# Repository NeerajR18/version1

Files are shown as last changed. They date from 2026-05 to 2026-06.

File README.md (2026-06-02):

Zine

# version1

version1 is a TKL(TenKeyLess) Mechanical Keyboard with Kalih Hotswappable sockets and Cherry MX Black switches.

The keyboard features a fully custom made PCB with 87 standard TKL keys and 4 macrokeys. The keyboard is wired, using a USB-C port.
version1 uses the STM32F072CBT6 at its core.

The PCB was designed in KiCad and the case was designed in Autodesk Fusion. Fusion was also used to render images of the design.
The footprints for the switches have been taken from the marbastlib library - https://github.com/ebastler/marbastlib

Made for Hack Club Fallout.
Note: This is still a WIP. Please copy anything at your own risk or do not copy at all.
## Why build this?
This keyboard was designed as a deep dive into electronics as a beginner and to learn more about CAD. 

I also have never used mechanical keyboards, so I want this to act as my entry point to mechanical keyboards.

## Repository Guide
```
version1/
|── PCB/
|   |── version1.kicad_pro
|   |── version1.kicad_pcb
|   |── version1.kicad_sch
|   └── version1_matrix.kicad_sch
|
|── CAD/
|   |── version1.f3d
|   |── version1-assembly.step
|   |── version1.fbx
|   |
|   |──── version1-base/
|   |     |── version1-base-left.step
|   |     |── version1-base-middle.step
|   |     └── version1-base-right.step
|   |
|   └──── version1-plate/
|         |── version1-plate-left.step
|         └── version1-plate-right.step
| 
|── Production/   
|    |── gerbers.zip/
|    |
|    |── STL Files/
|    |   |─── version1-base/
|    |   |    |── version1-base-left.stl
|    |   |    |── version1-base-middle.stl
|    |   |    └── version1-base-right.stl
|    |   |
|    |   └─── version1-plate/
|    |        |── version1-plate-left.stl
|    |        └── version1-plate-right.stl
|    |
|    └── STEP Files/
|           |─── version1-base/
|           |      |── version1-base-left.step
|           |      |── version1-base-middle.step
|           |      └── version1-base-right.step
|           |
|           └──── version1-plate/
|                   |── version1-plate-left.step
|                   └── version1-plate-right.step
|
|── Assets/
|    |── Keycaps/
|    |── MX Switch/
|    |── Rotary Encoder/
|    |── Type-C/
|    └── version1.fbx
|
|── qmk_firmware/
|    └── version1/
|       |── keymaps/
|       |   └── keymaps/
|       |       └── default/
|       |           └── keymap.c
|       |── config.h
|       |── keyboard.json
|       └── readme.md
|
|── BOM.csv
|── Zine.pdf
└── README.md
```

## Schematic
##### Overall Schematic


##### Key matrix


## PCB
##### PCB Front without GND Plane


##### PCB Front with GND Plane


##### PCB Back without GND Plane


##### PCB Back with GND Plane


## CAD
The case has been split into two parts on the plate and 3 parts on the base to accomodate 3D printed parts. The plates and base have small pegs and holes for assembly.

#### Full Assembly
##### Top View


#####  Side View


#### Top Plate
##### Top View


#####  Side View


#### Base
##### Top View


#####  Side View


## Renders 
##### Top view
version1-top-render

##### Side view
version1-side-render
version1-right-render

## Build Guide
To be updated with pictures after IRL build.

## Bill of Materials

| MPN | Designator | Quantity | Unit Price (USD) | Price (Ext.) | Package | LCSC Part Number | Link |
|-----|---|---|---|---|---|---|---|
| CPG151101S11-2 | MX1-M91 | 100 | 0.0344 | 3.44 | - | C49352235 | https://www.lcsc.com/product-detail/C49352235.html |
| STM32F072CBT6 | U1 | 1 | 2.212 | 2.21 | LQFP-48(7x7) | C81720 | https://www.lcsc.com/product-detail/C81720.html |
| XC6206P332MR-G | U2 | 5 | 0.1119 | 0.56 | SOT-23-3L | C5446 | https://www.lcsc.com/product-detail/C5446.html |
| PRTR5V0U2X-ES | D1 | 5 | 0.0404 | 0.2 | SOT-143 | C5180302 | https://www.lcsc.com/product-detail/C5180302.html |
| 1N4148W | D2-D93 | 100 | 0.0058 | 0.58 | SOD-123 | C917030 | https://www.lcsc.com/product-detail/C917030.html |
| TYPE-C 16PIN 2MD(073) | J1 | 20 | 0.0747 | 1.49 | SMD | C2765186 | https://www.lcsc.com/product-detail/C2765186.html |
| TS-1088-AR02016 | SW1, SW2 | 10 | 0.0538 | 0.54 | SMD, 4x3mm | C720477 | https://www.lcsc.com/product-detail/C720477.html |
| EC11E15244B2 | SW3 | 1 | 2 | 2 | Through Hole | C470754 | https://www.lcsc.com/product-detail/C470754.html |
| 1206L050YR | F1 | 10 | 0.0622 | 0.62 | 1206 | C163512 | https://www.lcsc.com/product-detail/C163512.html |
| RC0402FR-075K1L | R1, R2 | 100 | 0.0009 | 0.09 | 0402 | C105872 | https://www.lcsc.com/product-detail/C105872.html |
| RC0402FR-0710KL | R3 | 100 | 0.0008 | 0.08 | 0603 | C60490 | https://www.lcsc.com/product-detail/C60490.html |
| CC0402KRX7R7BB104 | C1, C4, C5, C6, C7, C8, C10 | 100 | 0.0011 | 0.11 | 0402 | C60474 | https://www.lcsc.com/product-detail/C60474.html |
| CL10B105KA8NNNC | C2, C3 | 50 | 0.0069 | 0.35 | 0603 | C29936 | https://www.lcsc.com/product-detail/C29936.html |
| CL10A106KP8NNNC | C9 | 50 | 0.0103 | 0.52 | 0603 | C19702 | https://www.lcsc.com/product-detail/C19702.html |
| Cherry MX Black Switches [Pack of 10] | - | 10 | 3.48 | 34.8 | - | - | https://neomacro.in/products/cherry-mx-switches?_pos=2&_sid=a9445e82d&_ss=r&variant=47150319108374 |
| Keycaps | - | 1 | 13.5 | 13.5 | - | - | https://stackskb.com/store/veekos-gradient-keycaps-cherry-profile-135-keys/ |
| Stabilizers (clip in) | - | 10 | 0.33 | 3.32 | - | - | https://neomacro.in/products/cherry-pcb-mount-stabilizers-clip-in?_pos=1&_sid=0547a7463&_ss=r |
| Wires for stabilizers | - | 1 | 4.16 | 4.16 | - | - | https://neomacro.in/products/equalz-c3-stabilizer-wire-set |
| M3x20mm Screws | - | 15 | 0.017 | 0.26 | - | - | https://omrook.com/ss-allen-csk-m3-x-20mm-dia-3mm-length-20mm-stainless-steel-ss202-allen-socket-countersunk-screws/ |
| M3x4 Brass Inserts | - | 50 | 0.023 | 1.15 | - | - | https://omrook.com/m3-x-4-brass-threaded-inserts-nut-50pc/ |
| Rotary Encoder Knob [Pack of 5] | - | 1 | 0.033 | 0.17 | - | - | https://makerbazar.in/products/black-rotary-encoder-knob-111-no |
| 1x4 Right Angle Berg Pin Header 2.54 mm pitch | J2 | 5 | 0.041 | 0.21 | - | - | https://sharvielectronics.com/product/4x1-4pin-male-right-angle-berg-header-connector-6mm-2-54mm-pitch/ |
| PCB - JLCPCB (with shipping) | - | 5 | 9.552 | 47.76 | - | - | https://jlcpcb.com/ |
| Total |  |  |  | 118.12 |  |  |  |

## Extras
### To be added in the future
- Angle adjustment
- Better case

### Resources I used for making this
- GrabCAD - https://grabcad.com/ [3D Models]
- marbastlib library - https://github.com/ebastler/marbastlib
- Noah Kiser on youtube - https://www.youtube.com/@noahkiser
- Keyboard Layout Editor - https://www.keyboard-layout-editor.com/
- ai03 Plate Generator - https://kbplate.ai03.com/
- MECH-TKL on cults3d - https://cults3d.com/en/3d-model/gadget/mechanical-keyboard-mech-tkl
- KiCad - https://www.kicad.org
- Keyboard Atelier discord server
- Autodesk Fusion - https://www.autodesk.com/products/fusion-360/personal
- Modern Hobbyist on YouTube - https://www.youtube.com/watch?v=u13yRbBiRYM
- iNimbleSloth on YouTube - https://www.youtube.com/watch?v=9bjp_LteX_Y
- Joe Scotto on YouTube - https://www.youtube.com/watch?v=o7SF2TPVV6o
- Hack Club and Fallout for funding - https://hackclub.com/
                                    - https://fallout.hackclub.com/

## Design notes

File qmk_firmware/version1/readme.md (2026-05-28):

# version1

version1

*A short description of the keyboard/project*

* Keyboard Maintainer: [Neeraj ](https://github.com/NeerajR18)
* Hardware Supported: *The PCBs, controllers supported*
* Hardware Availability: *Links to where you can find this hardware*

Make example for this keyboard (after setting up your build environment):

    make version1:default

Flashing example for this keyboard:

    make version1:default:flash

See the [build environment setup](https://docs.qmk.fm/#/getting_started_build_tools) and the [make instructions](https://docs.qmk.fm/#/getting_started_make_guide) for more information. Brand new to QMK? Start with our [Complete Newbs Guide](https://docs.qmk.fm/#/newbs).

## Bootloader

Enter the bootloader in 3 ways:

* **Bootmagic reset**: Hold down the key at (0,0) in the matrix (usually the top left key or Escape) and plug in the keyboard
* **Physical reset button**: Briefly press the button on the back of the PCB - some may have pads you must short instead
* **Keycode in layout**: Press the key mapped to `QK_BOOT` if it is available

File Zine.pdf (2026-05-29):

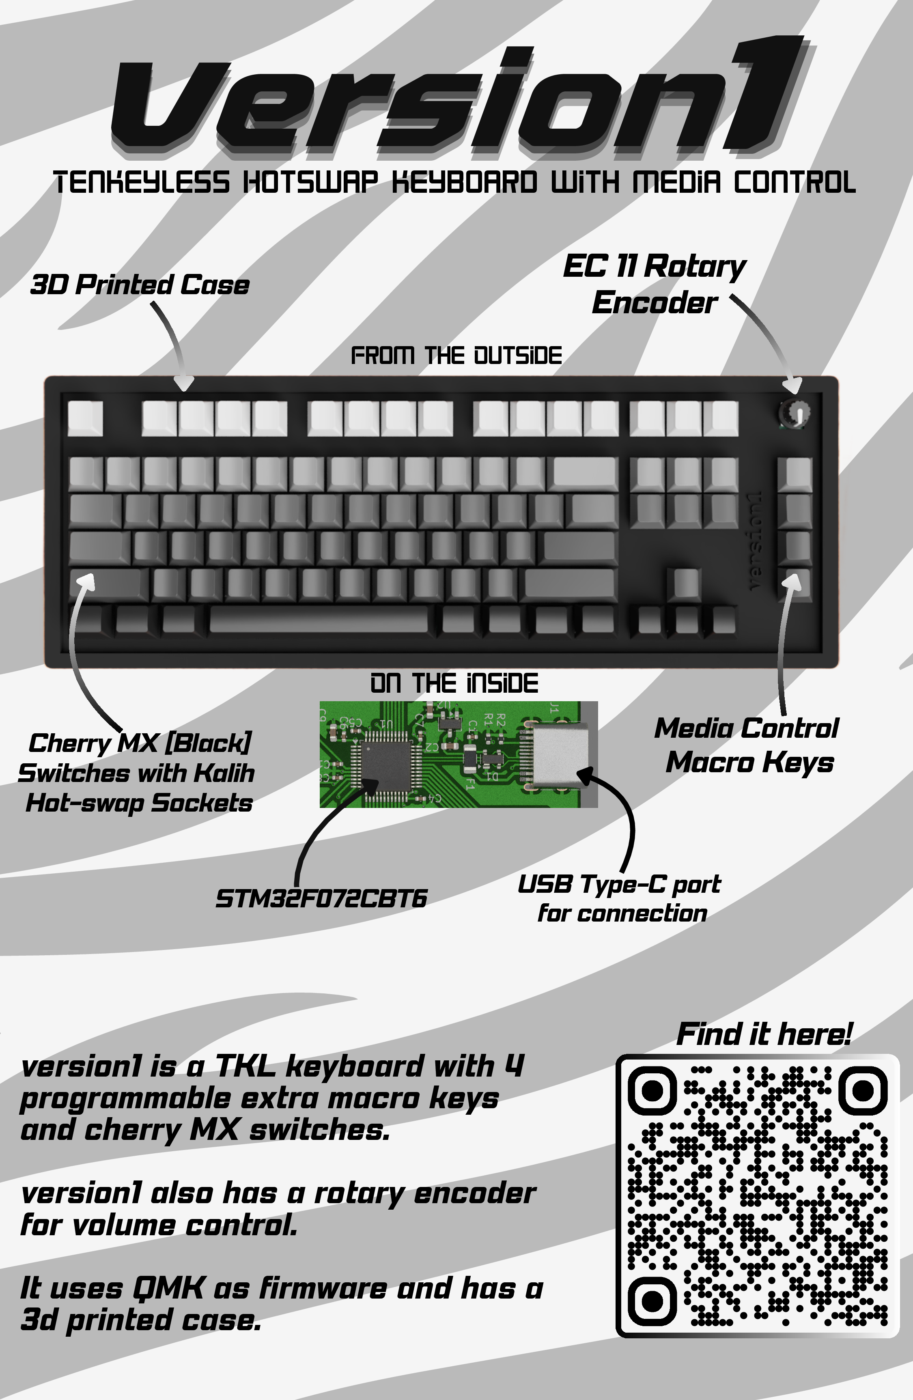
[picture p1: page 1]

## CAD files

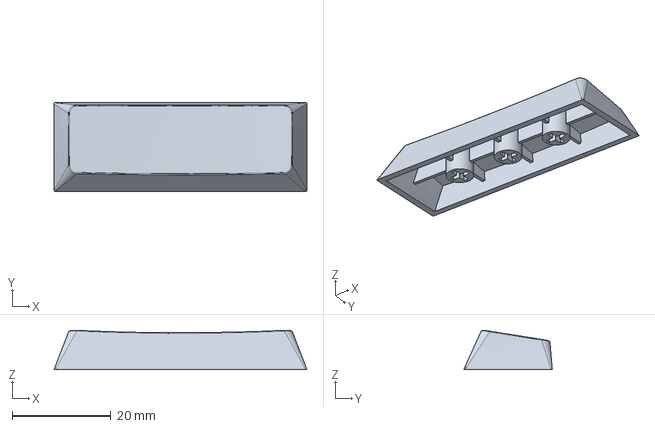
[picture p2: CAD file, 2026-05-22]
Assets/Keycaps/Rshift.step
51.3 x 18.0 x 8.00 mm

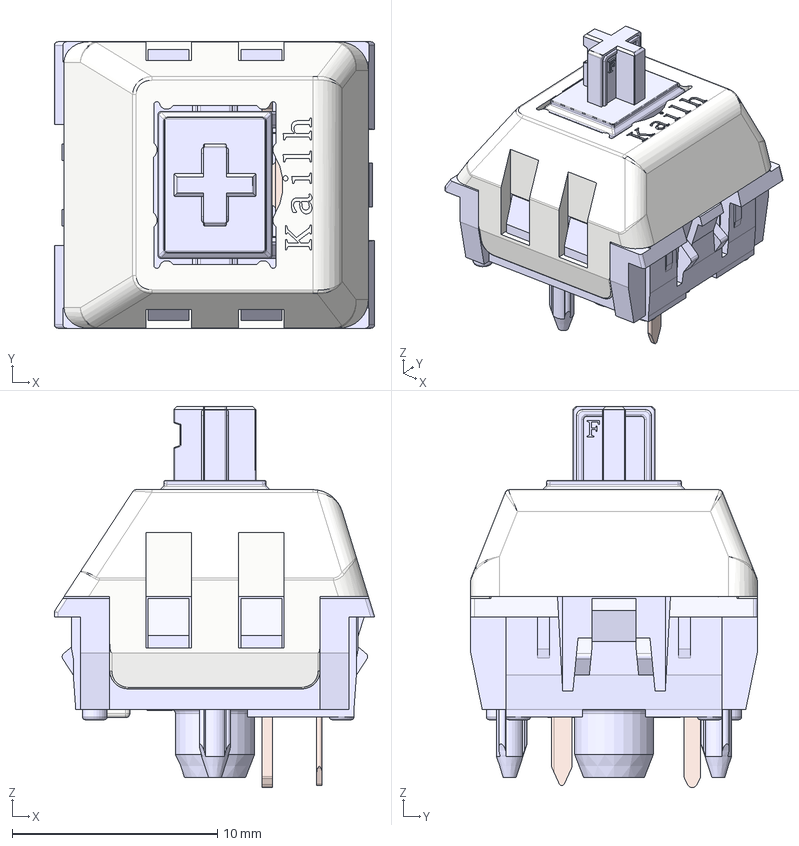
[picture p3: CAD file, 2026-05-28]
Assets/MX Switch/MX_Switch.step
15.6 x 14.0 x 18.5 mm
Housing
ThickContact
SpringContact
Stem
Lid

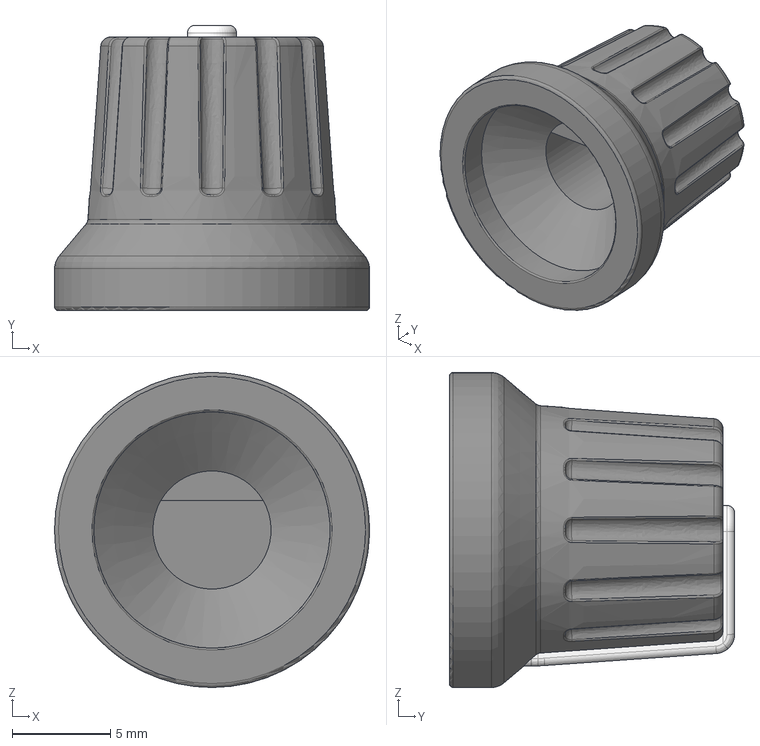
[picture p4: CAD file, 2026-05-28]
Assets/Rotary Encoder/Rotary Knob.step
16.0 x 14.5 x 16.0 mm

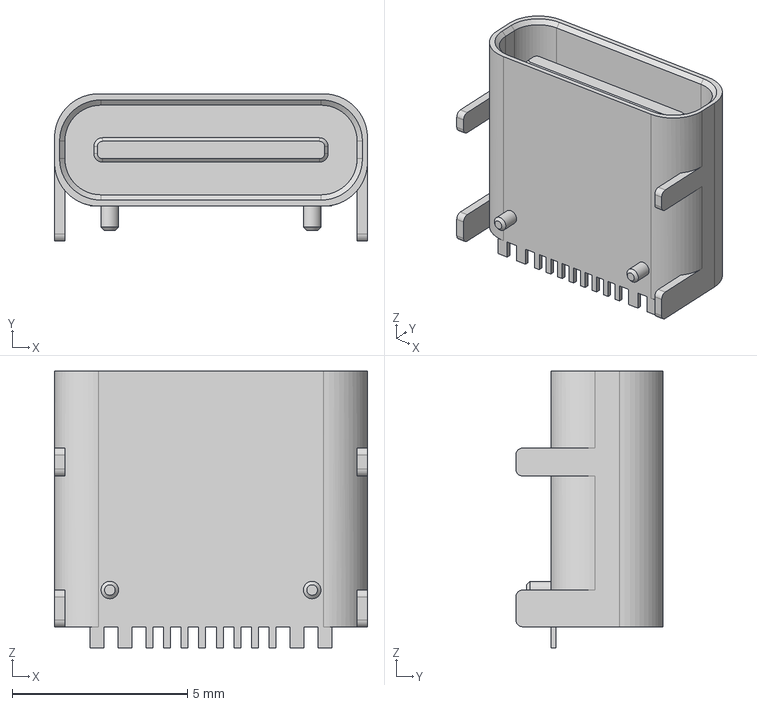
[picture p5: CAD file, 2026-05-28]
Assets/Type-C/HRO TYPE-C-31-M-12.step
8.94 x 4.21 x 7.90 mm

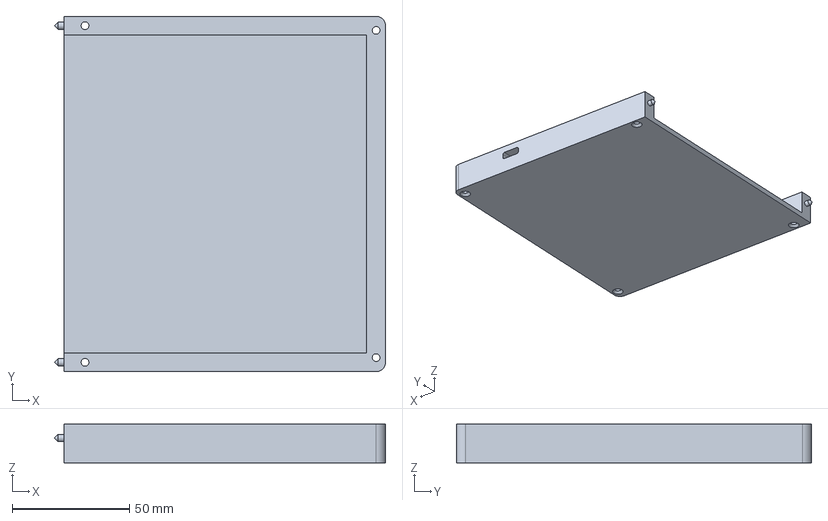
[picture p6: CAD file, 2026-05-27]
Production/STEP Files/version1-base/version1-base-right.step
141.0 x 151.4 x 16.5 mm
91294A136_Black-Oxide Alloy Steel Hex Drive Flat Head Screw
91294A136_Black-Oxide Alloy Steel Hex Drive Flat Head Screw_1 x 10

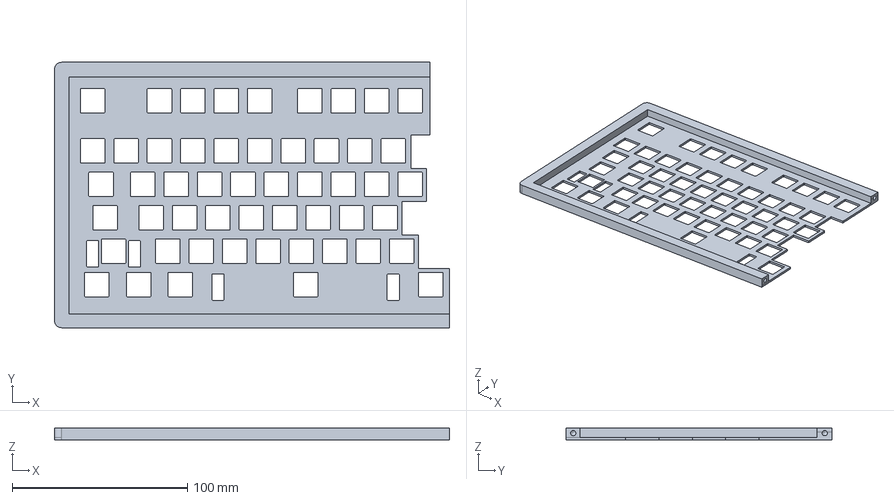
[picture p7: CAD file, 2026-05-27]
Production/STEP Files/version1-plate/version1-plate-left.step
225.2 x 151.4 x 7.00 mm
91294A136_Black-Oxide Alloy Steel Hex Drive Flat Head Screw
91294A136_Black-Oxide Alloy Steel Hex Drive Flat Head Screw_1 x 10

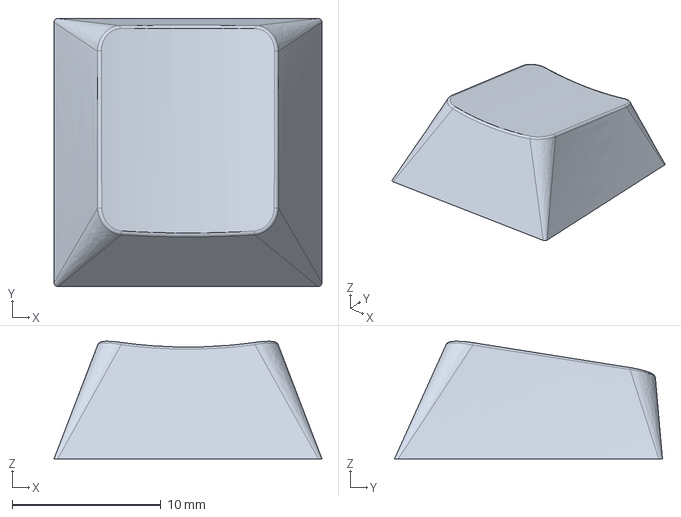
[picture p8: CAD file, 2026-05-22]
Assets/Keycaps/Qwerty.step
18.0 x 18.0 x 7.90 mm

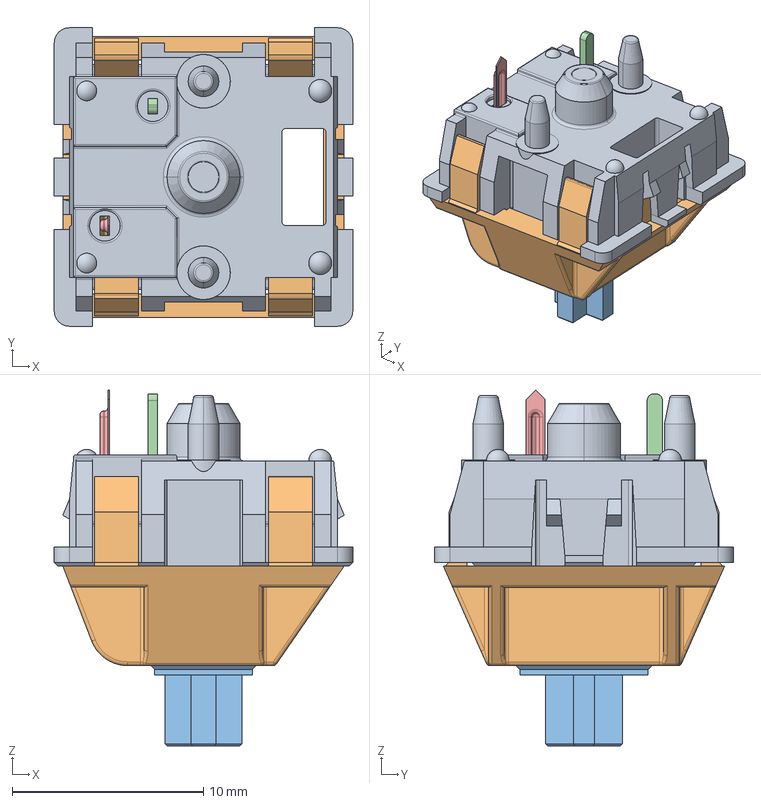
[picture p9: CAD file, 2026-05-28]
Assets/MX Switch/MX_switch_alternate.stp
15.6 x 15.6 x 18.6 mm
MX_DOWN
MX_UP
UP_MX
MX_PIN
MX_SPRING
MX_CLICK

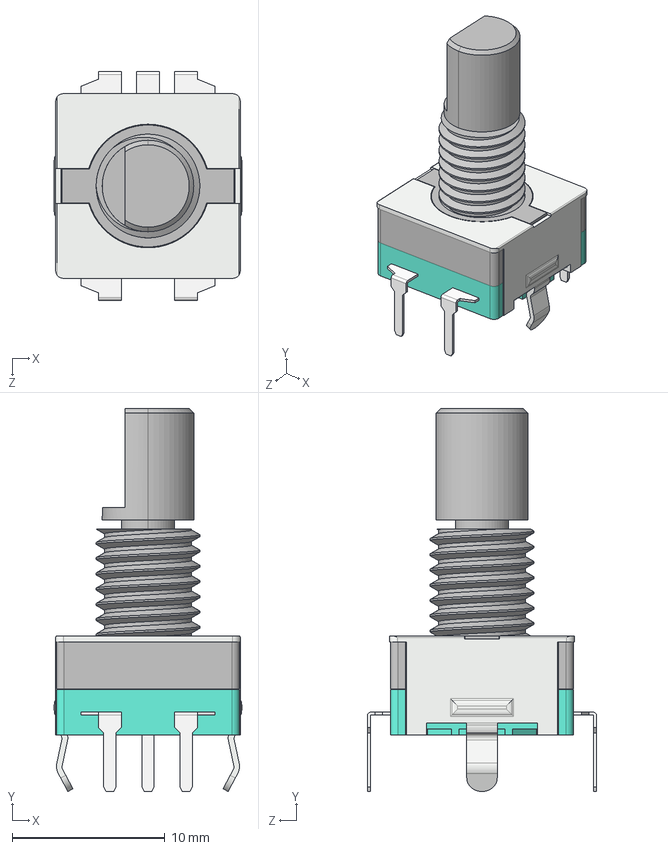
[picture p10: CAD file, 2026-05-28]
Assets/Rotary Encoder/Rotary_encoder.STEP
12.3 x 25.1 x 15.0 mm

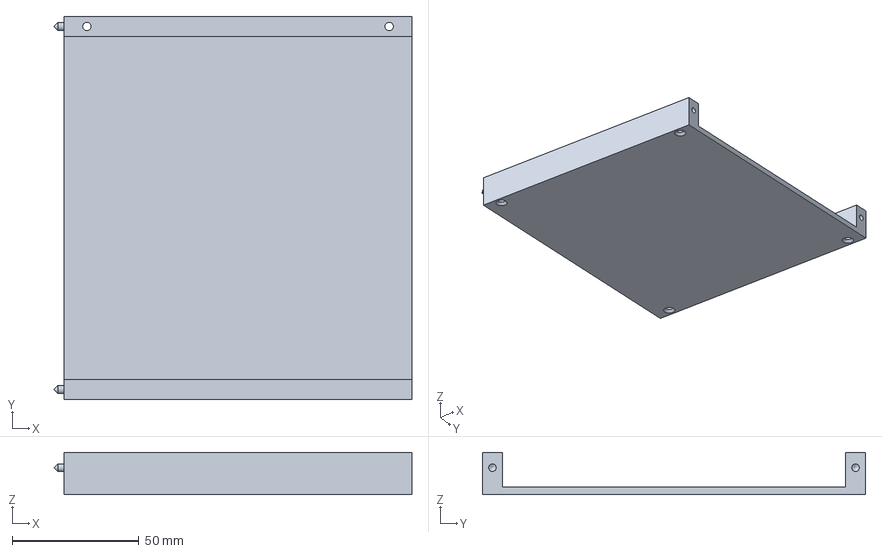
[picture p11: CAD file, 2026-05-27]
Production/STEP Files/version1-base/version1-base-middle.step
141.4 x 151.4 x 16.6 mm
91294A136_Black-Oxide Alloy Steel Hex Drive Flat Head Screw
91294A136_Black-Oxide Alloy Steel Hex Drive Flat Head Screw_1 x 10

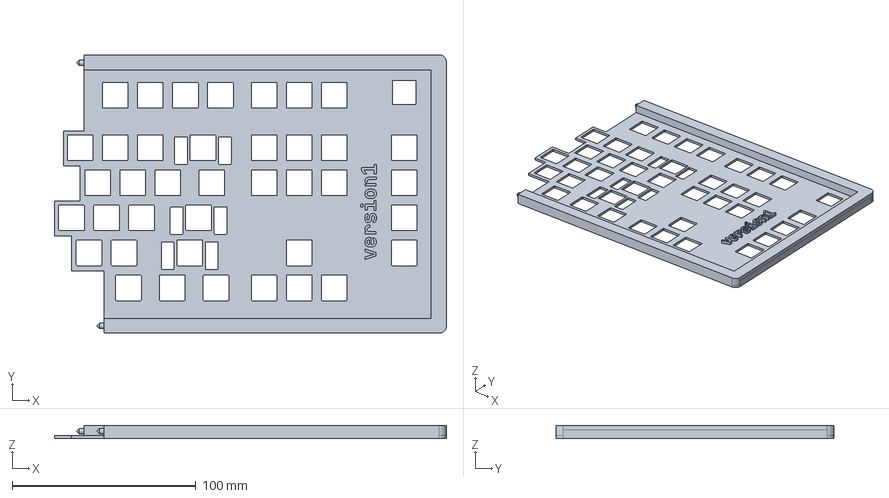
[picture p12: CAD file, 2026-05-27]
Production/STEP Files/version1-plate/version1-plate-right.step
213.2 x 151.4 x 7.06 mm
91294A136_Black-Oxide Alloy Steel Hex Drive Flat Head Screw
91294A136_Black-Oxide Alloy Steel Hex Drive Flat Head Screw_1 x 10

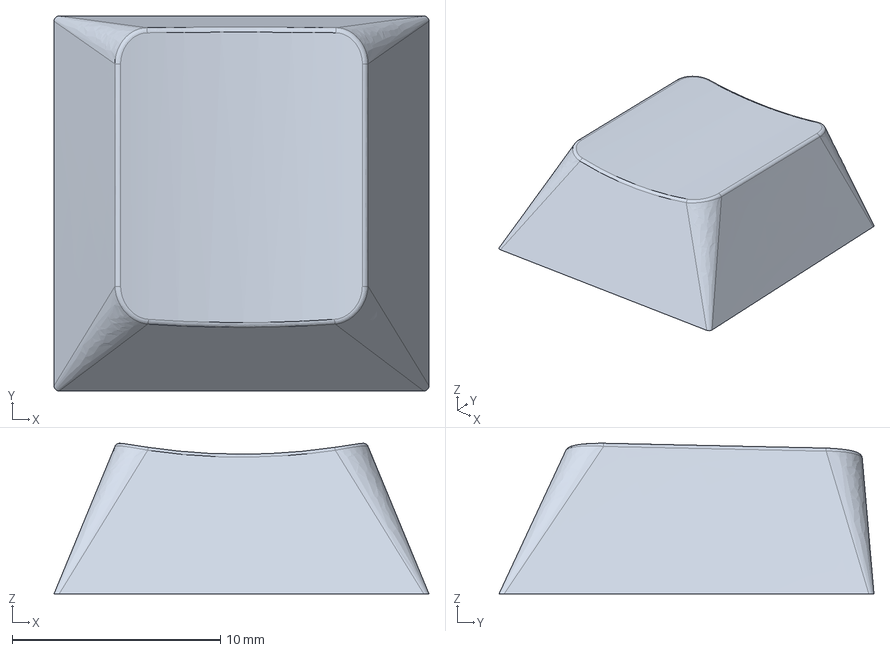
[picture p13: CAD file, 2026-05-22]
Assets/Keycaps/ROW_1_Numbers.step
18.0 x 18.0 x 7.23 mm

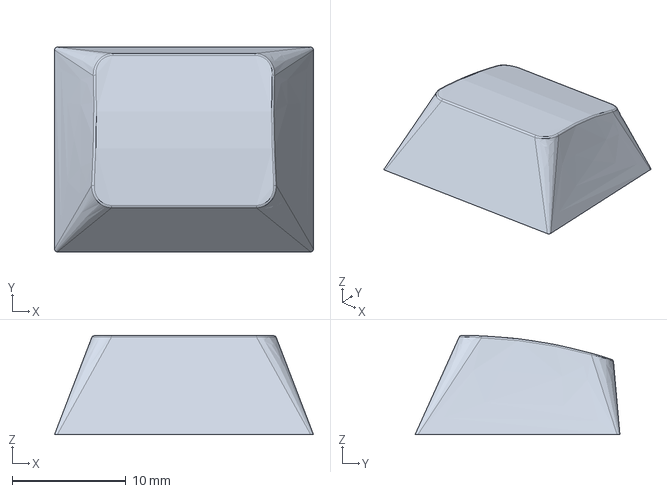
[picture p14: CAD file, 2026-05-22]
Assets/Keycaps/Bottom_row1u25.step
22.8 x 18.0 x 8.70 mm

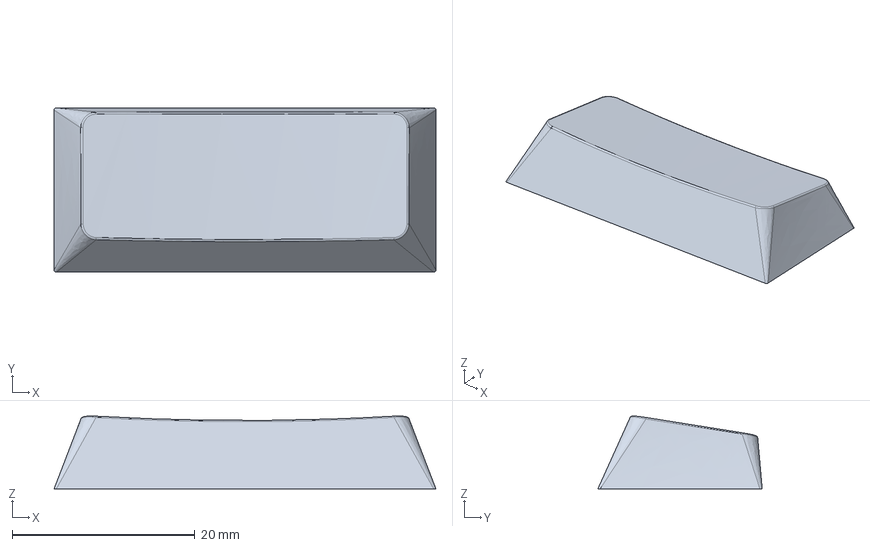
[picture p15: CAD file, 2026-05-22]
Assets/Keycaps/Enter_Lshift.step
41.8 x 18.0 x 7.99 mm

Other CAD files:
Production/STEP Files/version1-base/version1-base-left.step
Assets/Keycaps/Bottom_row1u.step
Assets/Keycaps/Tab_key.step
Assets/Keycaps/ESC_and_Function_keys.step
Assets/Keycaps/Back_sp.step
Assets/Keycaps/Backsp.step
Assets/Keycaps/Caps.step
Assets/Keycaps/Space_bar.step
Assets/Keycaps/middle_row.step
Production/STL Files/version1-base/version1-base-left.stl
Production/STL Files/version1-base/version1-base-middle.stl
Production/STL Files/version1-base/version1-base-right.stl
Production/STL Files/version1-plate/version1-plate-left.stl
Production/STL Files/version1-plate/version1-plate-right.stl

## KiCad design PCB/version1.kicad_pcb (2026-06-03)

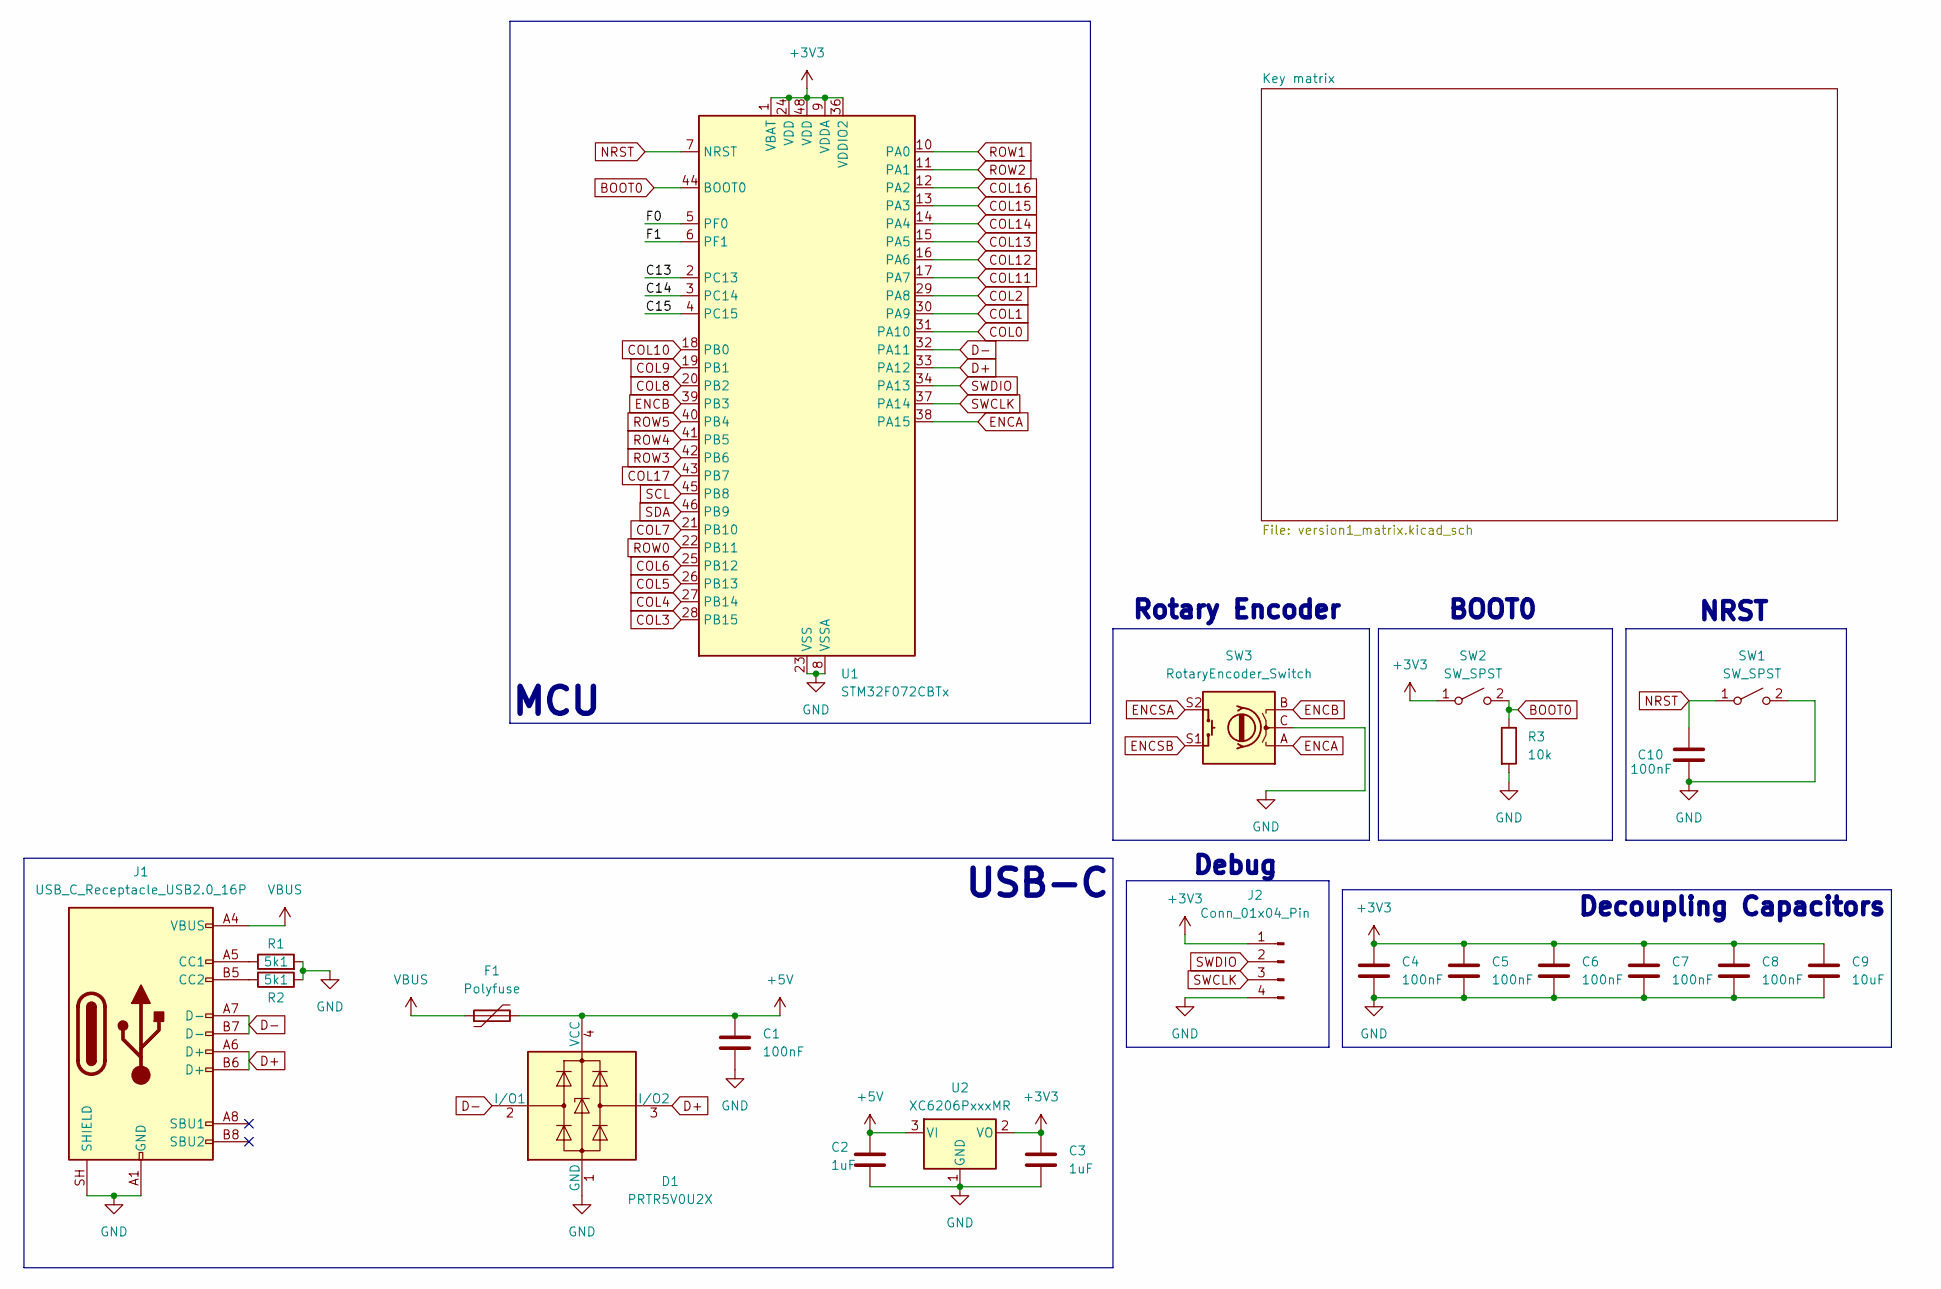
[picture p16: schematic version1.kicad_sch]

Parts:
C1, C4, C5, C6, C7, C8, C10: 100nF; C_0402_1005Metric
C2, C3: 1uF; C_0603_1608Metric
C9: 10uF; C_0603_1608Metric
D1: PRTR5V0U2X; SOT-143
F1: Polyfuse; Fuse_1206_3216Metric
J1: USB_C_Receptacle_USB2.0_16P; USB_C_Receptacle_HRO_TYPE-C-31-M-12
J2: Conn_01x04_Pin; PinHeader_1x04_P2.54mm_Horizontal
R1, R2: 5k1; R_0402_1005Metric
R3: 10k; R_0603_1608Metric
SW1, SW2: SW_SPST; SW_SPST_TS-1088-xR020
SW3: RotaryEncoder_Switch; RotaryEncoder_Alps_EC11E-Switch_Vertical_H20mm
U1: STM32F072CBTx; LQFP-48_7x7mm_P0.5mm
U2: XC6206PxxxMR; SOT-23-3

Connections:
+3V3: C3.1, C4.1, C5.1, C6.1, C7.1, C8.1, C9.1, J2.1, SW2.1 (A), U1.1 (VBAT), U1.9 (VDDA), U1.24 (VDD), U1.36 (VDDIO2), U1.48 (VDD), U2.2 (VO)
+5V: C1.1, C2.1, D1.4 (VCC), F1.2, U2.3 (VI)
/C13: U1.2 (PC13)
/C14: U1.3 (PC14)
/C15: U1.4 (PC15)
/F0: U1.5 (PF0)
/F1: U1.6 (PF1)
BOOT0: R3.1, SW2.2 (B), U1.44 (BOOT0)
COL0: U1.31 (PA10); also elsewhere on the board
COL1: U1.30 (PA9); also elsewhere on the board
COL2: U1.29 (PA8); also elsewhere on the board
COL3: U1.28 (PB15); also elsewhere on the board
COL4: U1.27 (PB14); also elsewhere on the board
COL5: U1.26 (PB13); also elsewhere on the board
COL6: U1.25 (PB12); also elsewhere on the board
COL7: U1.21 (PB10); also elsewhere on the board
COL8: U1.20 (PB2); also elsewhere on the board
COL9: U1.19 (PB1); also elsewhere on the board
COL10: U1.18 (PB0); also elsewhere on the board
COL11: U1.17 (PA7); also elsewhere on the board
COL12: U1.16 (PA6); also elsewhere on the board
COL13: U1.15 (PA5); also elsewhere on the board
COL14: U1.14 (PA4); also elsewhere on the board
COL15: U1.13 (PA3); also elsewhere on the board
COL16: U1.12 (PA2); also elsewhere on the board
COL17: SW3.S1, U1.43 (PB7); also elsewhere on the board
D+: D1.3 (I/O2), J1.A6 (D+), J1.B6 (D+), U1.33 (PA12)
D-: D1.2 (I/O1), J1.A7 (D-), J1.B7 (D-), U1.32 (PA11)
ENCA: SW3.A, U1.38 (PA15)
ENCB: SW3.B, U1.39 (PB3)
ENCSA: SW3.S2; also elsewhere on the board
GND: C1.2, C2.2, C3.2, C4.2, C5.2, C6.2, C7.2, C8.2, C9.2, C10.2, D1.1 (GND), J1.A1 (GND), J1.A12 (GND), J1.B1 (GND), J1.B12 (GND), J1.SH (SHIELD), J2.4, R1.2, R2.1, R3.2, SW1.2 (B), SW3.C, U1.8 (VSSA), U1.23 (VSS), U1.35 (VSS), U1.47 (VSS), U2.1 (GND)
NRST: C10.1, SW1.1 (A), U1.7 (NRST)
unnamed: J1.A5 (CC1), R1.1
unnamed: J1.B5 (CC2), R2.2
ROW0: U1.22 (PB11); also elsewhere on the board
ROW1: U1.10 (PA0); also elsewhere on the board
ROW2: U1.11 (PA1); also elsewhere on the board
ROW3: U1.42 (PB6); also elsewhere on the board
ROW4: U1.41 (PB5); also elsewhere on the board
ROW5: U1.40 (PB4); also elsewhere on the board
SCL: U1.45 (PB8)
SDA: U1.46 (PB9)
SWCLK: J2.3, U1.37 (PA14)
SWDIO: J2.2, U1.34 (PA13)
VBUS: F1.1, J1.A4 (VBUS), J1.A9 (VBUS), J1.B4 (VBUS), J1.B9 (VBUS)

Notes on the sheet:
BOOT0
Debug
MCU
Rotary Encoder
NRST
USB-C
Decoupling Capacitors

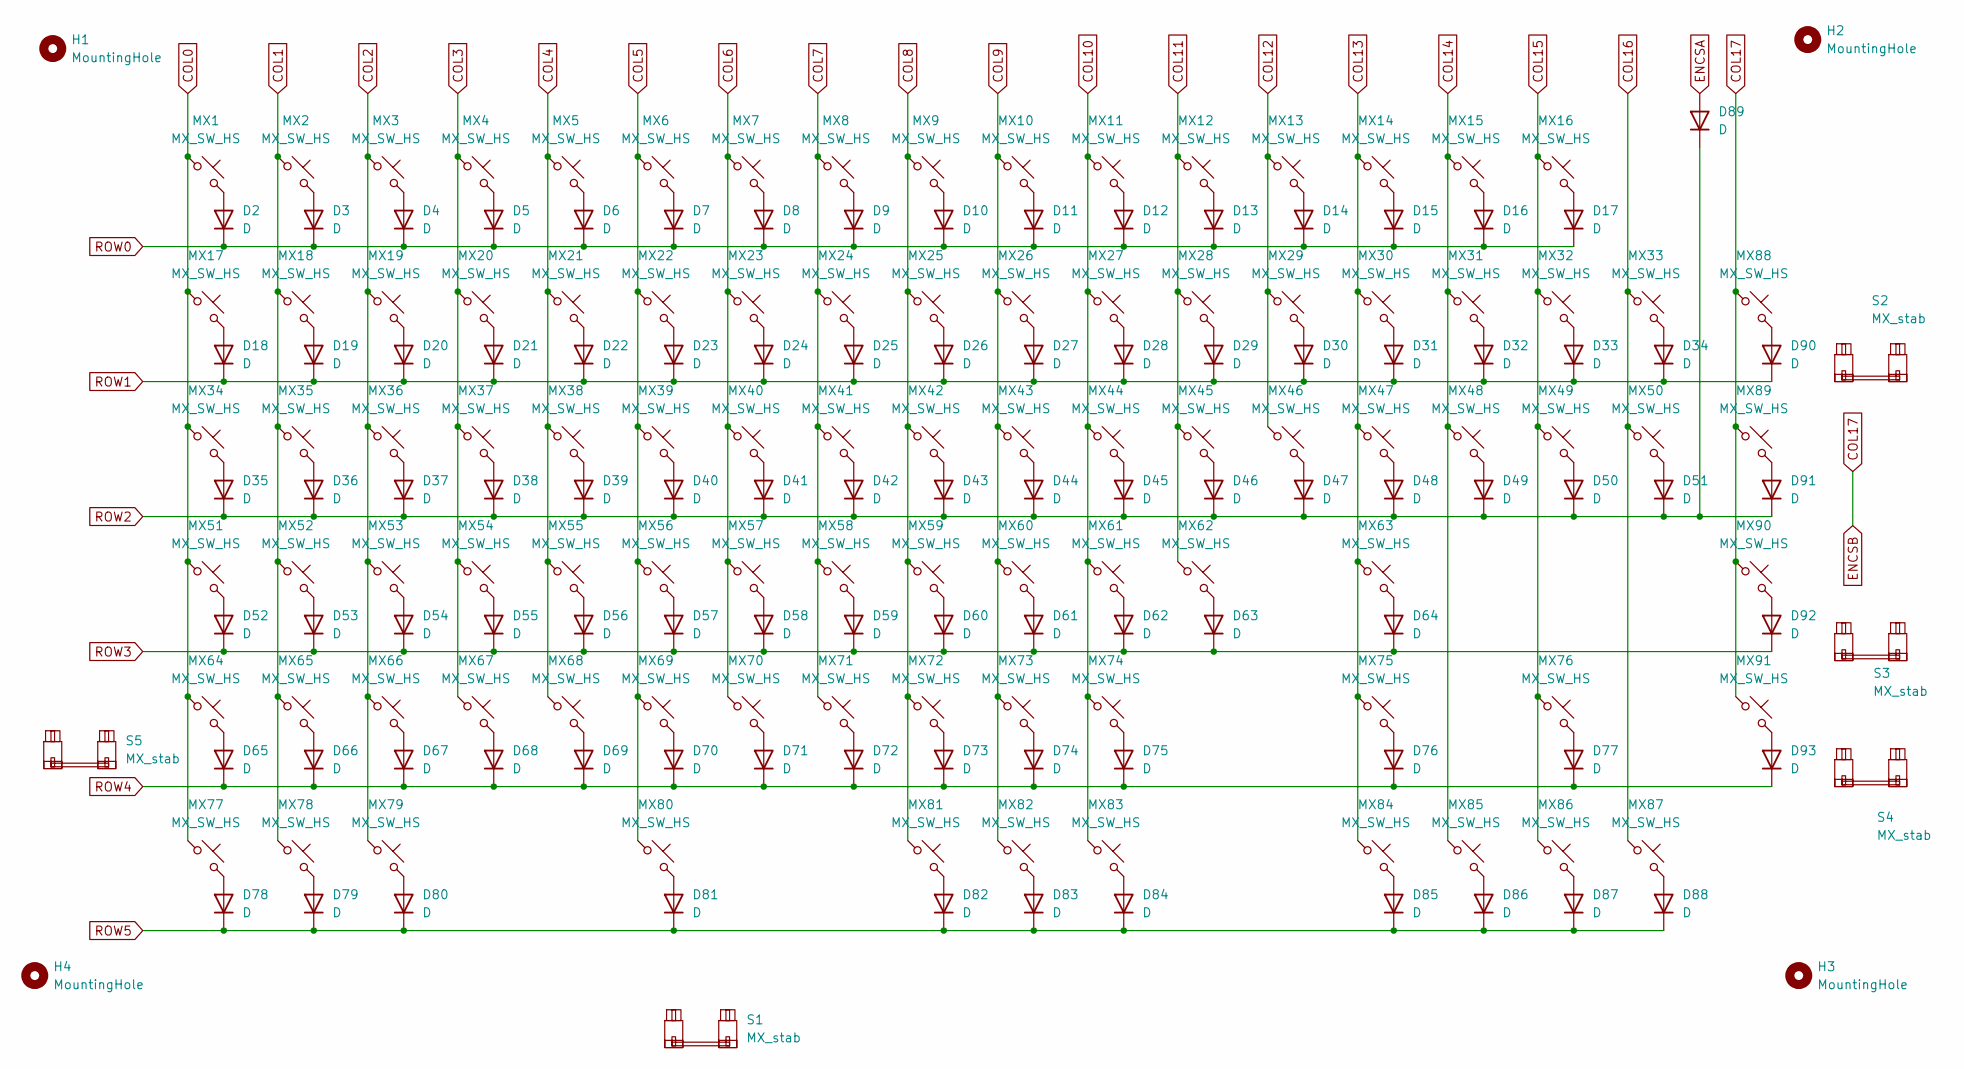
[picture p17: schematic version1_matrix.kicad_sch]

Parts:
D2, D3, D4, D5, D6, D7, D8, D9, D10, D11, D12, D13, D14, D15, D16, D17, D18, D19, D20, D21, D22, D23, D24, D25, D26, D27, D28, D29, D30, D31, D32, D33, D34, D35, D36, D37, D38, D39, D40, D41, D42, D43, D44, D45, D46, D47, D48, D49, D50, D51, D52, D53, D54, D55, D56, D57, D58, D59, D60, D61, D62, D63, D64, D65, D66, D67, D68, D69, D70, D71, D72, D73, D74, D75, D76, D77, D78, D79, D80, D81, D82, D83, D84, D85, D86, D87, D88, D89, D90, D91, D92, D93: D; D_SOD-123
H1, H2, H3, H4: MountingHole; MountingHole_2mm
MX1, MX2, MX3, MX4, MX5, MX6, MX7, MX8, MX9, MX10, MX11, MX12, MX13, MX14, MX15, MX16, MX17, MX18, MX19, MX20, MX21, MX22, MX23, MX24, MX25, MX26, MX27, MX28, MX29, MX30, MX31, MX32, MX33, MX35, MX36, MX37, MX38, MX39, MX40, MX41, MX42, MX43, MX44, MX45, MX46, MX48, MX49, MX50, MX52, MX53, MX54, MX55, MX56, MX57, MX58, MX59, MX60, MX61, MX62, MX63, MX64, MX65, MX66, MX67, MX68, MX69, MX70, MX71, MX72, MX73, MX74, MX75, MX76, MX80, MX85, MX86, MX87, MX88, MX89, MX90, MX91: MX_SW_HS; SW_MX_HS_CPG151101S11_1u
MX34, MX47: MX_SW_HS; SW_MX_HS_CPG151101S11_1.5u
MX51: MX_SW_HS; SW_MX_HS_CPG151101S11_1.75u
MX77, MX78, MX79, MX81, MX82, MX83, MX84: MX_SW_HS; SW_MX_HS_CPG151101S11_1.25u
S1: MX_stab; STAB_MX_6.25u
S2, S3: MX_stab; STAB_MX_2.25u
S4: MX_stab; STAB_MX_2.75u
S5: MX_stab; STAB_MX_2u

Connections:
COL0: MX1.1, MX17.1, MX34.1, MX51.1, MX64.1, MX77.1; also elsewhere on the board
COL1: MX2.1, MX18.1, MX35.1, MX52.1, MX65.1, MX78.1; also elsewhere on the board
COL2: MX3.1, MX19.1, MX36.1, MX53.1, MX66.1, MX79.1; also elsewhere on the board
COL3: MX4.1, MX20.1, MX37.1, MX54.1, MX67.1; also elsewhere on the board
COL4: MX5.1, MX21.1, MX38.1, MX55.1, MX68.1; also elsewhere on the board
COL5: MX6.1, MX22.1, MX39.1, MX56.1, MX69.1, MX80.1; also elsewhere on the board
COL6: MX7.1, MX23.1, MX40.1, MX57.1, MX70.1; also elsewhere on the board
COL7: MX8.1, MX24.1, MX41.1, MX58.1, MX71.1; also elsewhere on the board
COL8: MX9.1, MX25.1, MX42.1, MX59.1, MX72.1, MX81.1; also elsewhere on the board
COL9: MX10.1, MX26.1, MX43.1, MX60.1, MX73.1, MX82.1; also elsewhere on the board
COL10: MX11.1, MX27.1, MX44.1, MX61.1, MX74.1, MX83.1; also elsewhere on the board
COL11: MX12.1, MX28.1, MX45.1, MX62.1; also elsewhere on the board
COL12: MX13.1, MX29.1, MX46.1; also elsewhere on the board
COL13: MX14.1, MX30.1, MX47.1, MX63.1, MX75.1, MX84.1; also elsewhere on the board
COL14: MX15.1, MX31.1, MX48.1, MX85.1; also elsewhere on the board
COL15: MX16.1, MX32.1, MX49.1, MX76.1, MX86.1; also elsewhere on the board
COL16: MX33.1, MX50.1, MX87.1; also elsewhere on the board
COL17: MX88.1, MX89.1, MX90.1, MX91.1; also elsewhere on the board
ENCSA: D89.2 (A); also elsewhere on the board
unnamed: D2.2 (A), MX1.2
unnamed: D3.2 (A), MX2.2
unnamed: D4.2 (A), MX3.2
unnamed: D5.2 (A), MX4.2
unnamed: D6.2 (A), MX5.2
unnamed: D7.2 (A), MX6.2
unnamed: D8.2 (A), MX7.2
unnamed: D9.2 (A), MX8.2
unnamed: D10.2 (A), MX9.2
unnamed: D11.2 (A), MX10.2
unnamed: D12.2 (A), MX11.2
unnamed: D13.2 (A), MX12.2
unnamed: D14.2 (A), MX13.2
unnamed: D15.2 (A), MX14.2
unnamed: D16.2 (A), MX15.2
unnamed: D17.2 (A), MX16.2
unnamed: D18.2 (A), MX17.2
unnamed: D19.2 (A), MX18.2
unnamed: D20.2 (A), MX19.2
unnamed: D21.2 (A), MX20.2
unnamed: D22.2 (A), MX21.2
unnamed: D23.2 (A), MX22.2
unnamed: D24.2 (A), MX23.2
unnamed: D25.2 (A), MX24.2
unnamed: D26.2 (A), MX25.2
unnamed: D27.2 (A), MX26.2
unnamed: D28.2 (A), MX27.2
unnamed: D29.2 (A), MX28.2
unnamed: D30.2 (A), MX29.2
unnamed: D31.2 (A), MX30.2
unnamed: D32.2 (A), MX31.2
unnamed: D33.2 (A), MX32.2
unnamed: D34.2 (A), MX33.2
unnamed: D35.2 (A), MX34.2
unnamed: D36.2 (A), MX35.2
unnamed: D37.2 (A), MX36.2
unnamed: D38.2 (A), MX37.2
unnamed: D39.2 (A), MX38.2
unnamed: D40.2 (A), MX39.2
unnamed: D41.2 (A), MX40.2
unnamed: D42.2 (A), MX41.2
unnamed: D43.2 (A), MX42.2
unnamed: D44.2 (A), MX43.2
unnamed: D45.2 (A), MX44.2
unnamed: D46.2 (A), MX45.2
unnamed: D47.2 (A), MX46.2
unnamed: D48.2 (A), MX47.2
unnamed: D49.2 (A), MX48.2
unnamed: D50.2 (A), MX49.2
unnamed: D51.2 (A), MX50.2
unnamed: D52.2 (A), MX51.2
unnamed: D53.2 (A), MX52.2
unnamed: D54.2 (A), MX53.2
unnamed: D55.2 (A), MX54.2
unnamed: D56.2 (A), MX55.2
unnamed: D57.2 (A), MX56.2
unnamed: D58.2 (A), MX57.2
unnamed: D59.2 (A), MX58.2
unnamed: D60.2 (A), MX59.2
unnamed: D61.2 (A), MX60.2
unnamed: D62.2 (A), MX61.2
unnamed: D63.2 (A), MX62.2
unnamed: D64.2 (A), MX63.2
unnamed: D65.2 (A), MX64.2
unnamed: D66.2 (A), MX65.2
unnamed: D67.2 (A), MX66.2
unnamed: D68.2 (A), MX67.2
unnamed: D69.2 (A), MX68.2
unnamed: D70.2 (A), MX69.2
unnamed: D71.2 (A), MX70.2
unnamed: D72.2 (A), MX71.2
unnamed: D73.2 (A), MX72.2
unnamed: D74.2 (A), MX73.2
unnamed: D75.2 (A), MX74.2
unnamed: D76.2 (A), MX75.2
unnamed: D77.2 (A), MX76.2
unnamed: D78.2 (A), MX77.2
unnamed: D79.2 (A), MX78.2
unnamed: D80.2 (A), MX79.2
unnamed: D81.2 (A), MX80.2
unnamed: D82.2 (A), MX81.2
unnamed: D83.2 (A), MX82.2
unnamed: D84.2 (A), MX83.2
unnamed: D85.2 (A), MX84.2
unnamed: D86.2 (A), MX85.2
unnamed: D87.2 (A), MX86.2
unnamed: D88.2 (A), MX87.2
unnamed: D90.2 (A), MX88.2
unnamed: D91.2 (A), MX89.2
unnamed: D92.2 (A), MX90.2
unnamed: D93.2 (A), MX91.2
ROW0: D2.1 (K), D3.1 (K), D4.1 (K), D5.1 (K), D6.1 (K), D7.1 (K), D8.1 (K), D9.1 (K), D10.1 (K), D11.1 (K), D12.1 (K), D13.1 (K), D14.1 (K), D15.1 (K), D16.1 (K), D17.1 (K); also elsewhere on the board
ROW1: D18.1 (K), D19.1 (K), D20.1 (K), D21.1 (K), D22.1 (K), D23.1 (K), D24.1 (K), D25.1 (K), D26.1 (K), D27.1 (K), D28.1 (K), D29.1 (K), D30.1 (K), D31.1 (K), D32.1 (K), D33.1 (K), D34.1 (K), D90.1 (K); also elsewhere on the board
ROW2: D35.1 (K), D36.1 (K), D37.1 (K), D38.1 (K), D39.1 (K), D40.1 (K), D41.1 (K), D42.1 (K), D43.1 (K), D44.1 (K), D45.1 (K), D46.1 (K), D47.1 (K), D48.1 (K), D49.1 (K), D50.1 (K), D51.1 (K), D89.1 (K), D91.1 (K); also elsewhere on the board
ROW3: D52.1 (K), D53.1 (K), D54.1 (K), D55.1 (K), D56.1 (K), D57.1 (K), D58.1 (K), D59.1 (K), D60.1 (K), D61.1 (K), D62.1 (K), D63.1 (K), D64.1 (K), D92.1 (K); also elsewhere on the board
ROW4: D65.1 (K), D66.1 (K), D67.1 (K), D68.1 (K), D69.1 (K), D70.1 (K), D71.1 (K), D72.1 (K), D73.1 (K), D74.1 (K), D75.1 (K), D76.1 (K), D77.1 (K), D93.1 (K); also elsewhere on the board
ROW5: D78.1 (K), D79.1 (K), D80.1 (K), D81.1 (K), D82.1 (K), D83.1 (K), D84.1 (K), D85.1 (K), D86.1 (K), D87.1 (K), D88.1 (K); also elsewhere on the board

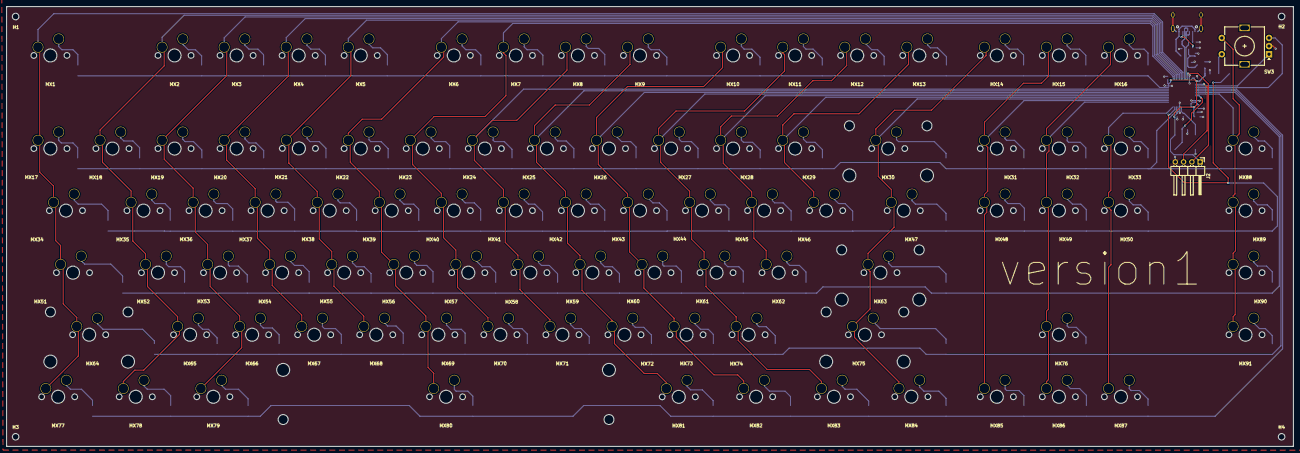
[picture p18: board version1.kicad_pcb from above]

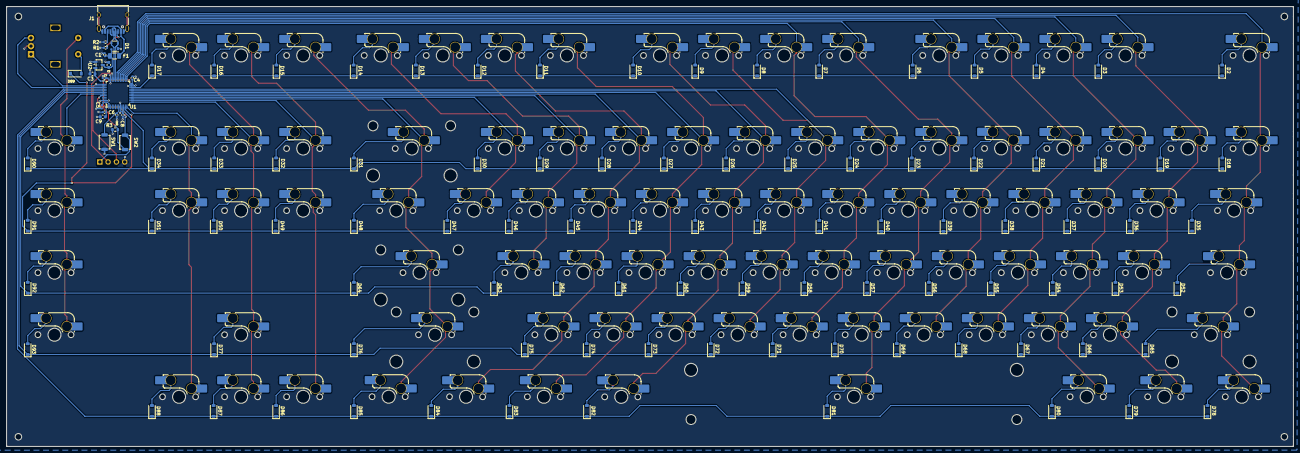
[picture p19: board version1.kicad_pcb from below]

Board: 2 copper layers, 395.0 x 135.0 mm, 214 parts (203 on the bottom side), 130 nets.

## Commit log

2026-05-15 Added folders and PCB files
    Added KiCad PCB files along with gerbers
    [version1.kicad_sch, version1_matrix.kicad_sch]
2026-05-16 Updated PCB and gerbers
    [version1.kicad_sch]
2026-05-21 Added CAD files
    [version1-base-left.step, version1-base-middle.step, version1-base-right.step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]
2026-05-21 PCB and gerbers with BOM
    Added KiCad Project files along with gerbers for production and Bill of Materials
    [BOM.csv, version1.kicad_sch]
2026-05-22 Added 3D models for keycaps
    [Back_sp.step, Backsp.step, Bottom_row1u.step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]
2026-05-27 Added updated CAD files and BOM.csv
    [BOM.csv, version1-base-left.step, version1-base-middle.step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]
2026-05-28 Updated PCB, gerbers and added STEP files to production folder
    [version1-base-left.step, version1-base-middle.step, version1-base-right.step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]
2026-05-28 Added stl files and other 3d models
    [HRO TYPE-C-31-M-12.step, MX_Switch.step, MX_switch_alternate.stp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]
2026-05-28 Updated schematic
    [version1.kicad_sch]
2026-05-28 Updated BOM.csv
    [BOM.csv]
2026-05-29 Updated BOM and readme
    [BOM.csv]
2026-06-02 Updated PCB files
    [version1.kicad_pcb, version1.kicad_sch]
2026-06-02 Updated PCB images and BOM
2026-06-02 minor changes
    [version1.kicad_sch]
2026-06-03 Minor PCB silkscreen changes with updated gerbers
    [version1.kicad_pcb]
